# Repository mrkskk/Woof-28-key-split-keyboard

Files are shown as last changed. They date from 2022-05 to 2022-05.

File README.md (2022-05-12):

# Woof-28-key-split-keyboard

## Description

If you hate moving your entire hand to reach keys, this 28-key collumnar staggered keyboard is for you.

It lacks the inner index collumn, and the upper pinky key has been moved to an easier to reach position. 

## Photos:

woof
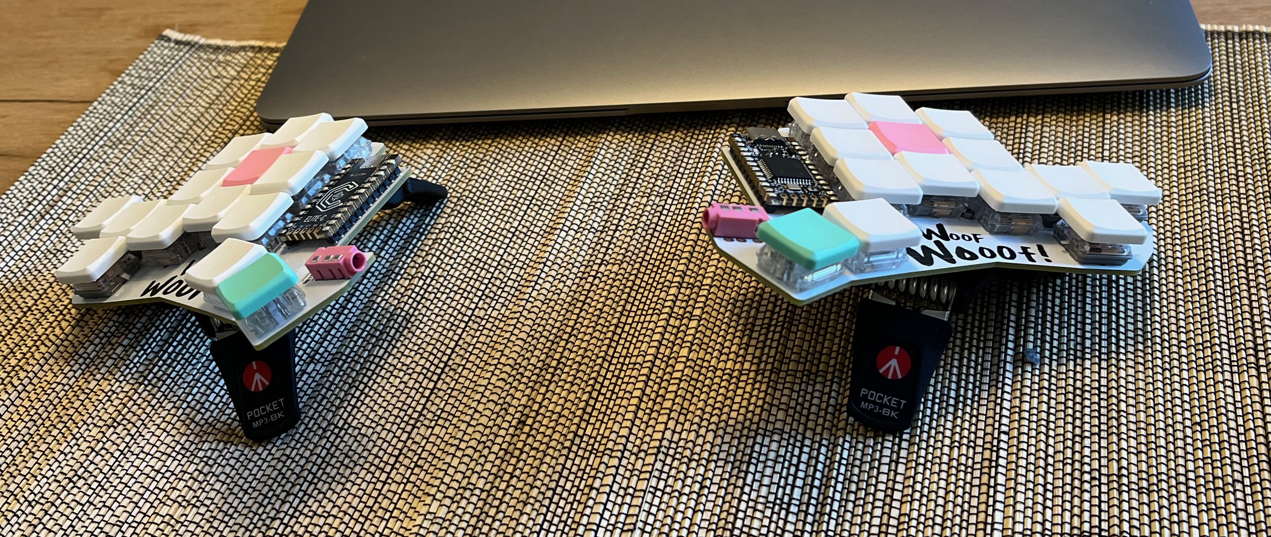
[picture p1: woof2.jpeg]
woof2

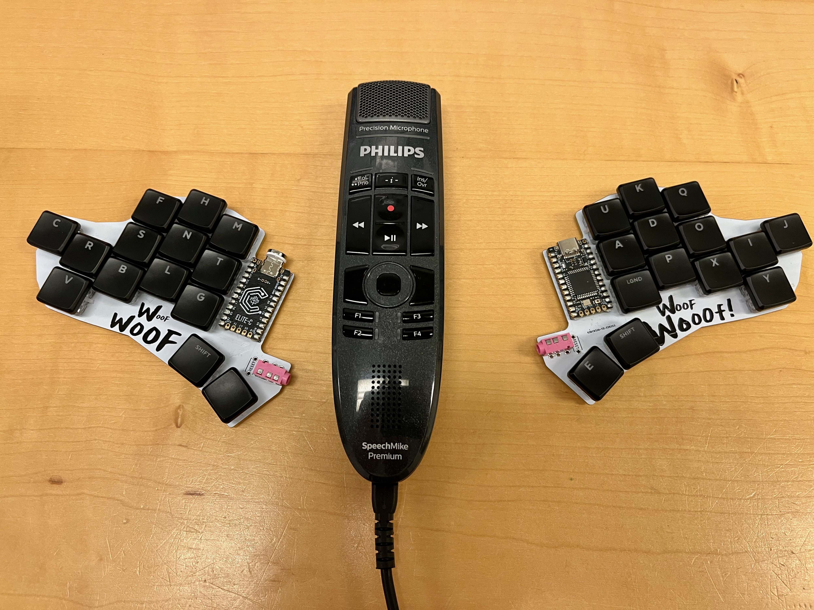
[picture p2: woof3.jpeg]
woof3


## Design Inspiration:

I named it woof since it sort of looks like a dog's head.

The keyboard uses the same staggering and keyspacing as the Ferris keyboard, but the inner index collumns have been removed. 

The upper row pinky keys have been moved to a position thats easier to reach. This is inspired by the Osprette, although the upper pinky key positions aren't the same.

Links:
* [Ferris, 34-key choc spaced keyboard](https://github.com/pierrechevalier83/ferris)
* [Osprette, 34-key unibody keyboard with pinky clusters](https://github.com/smores56/osprette)

## How to Print the circuit board

1. Download the gerber.zip file
2. Send it to a PCB manufacturer of your choice.
3. Pay and wait in patience

## How to build it

### Hardware requirements

* the PCB uploaded here
* Choc switches
* Choc compatible keycaps
* MCU: any ProMicro based MCU
* Optional: Battery, TRRS switch, TRRS cable, reset switch, 

### How to install the firmware

Either:
1. Use QMK. see my keymap below
OR
2. Use ZMK and make your own shield. the ZMK keymap is yet to be made

## My keymap

[QMK keymap](https://github.com/mrkskk/qmk_firmware/tree/my_branch/keyboards/woof)

## License
It is fully Open-Sourced.

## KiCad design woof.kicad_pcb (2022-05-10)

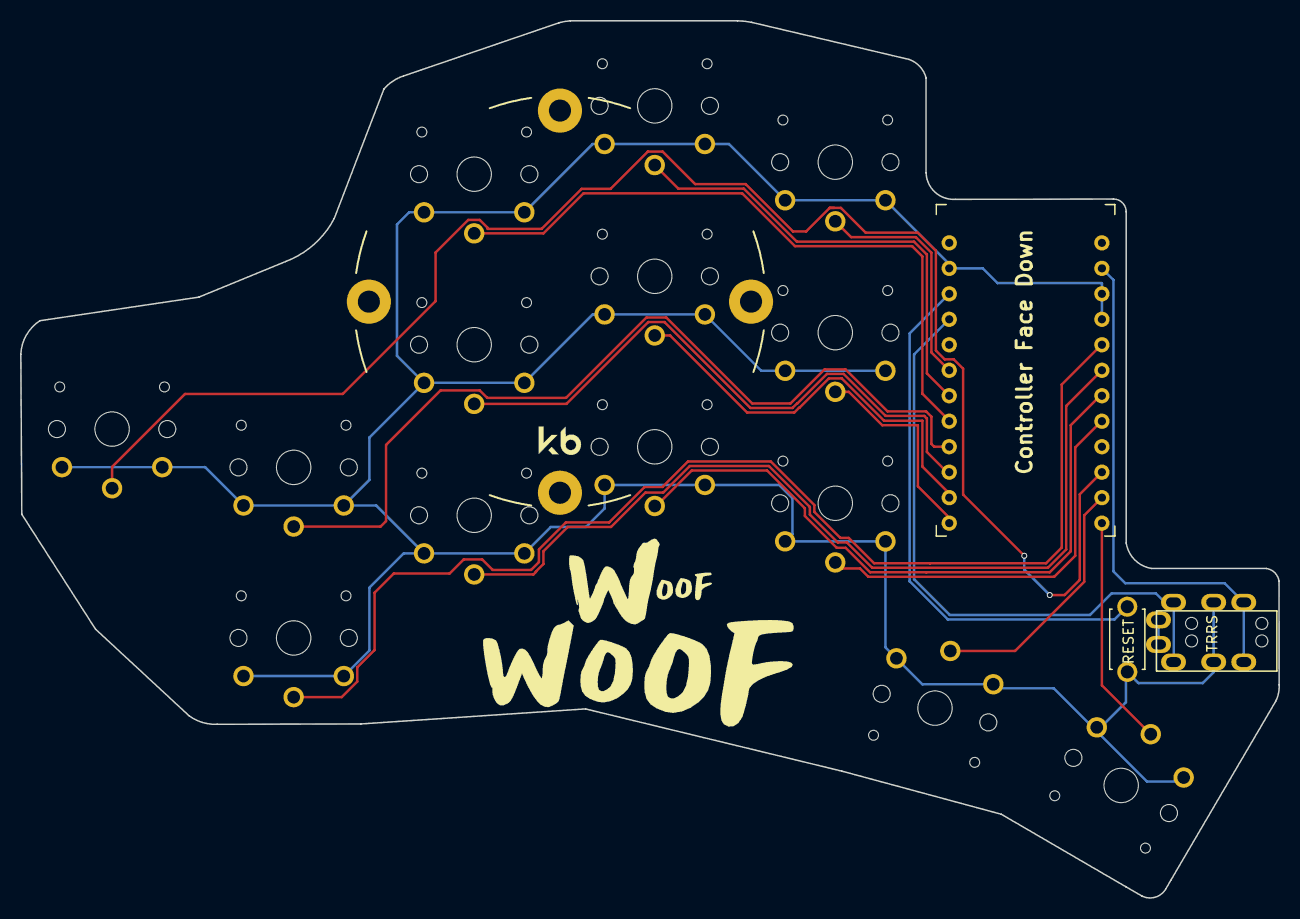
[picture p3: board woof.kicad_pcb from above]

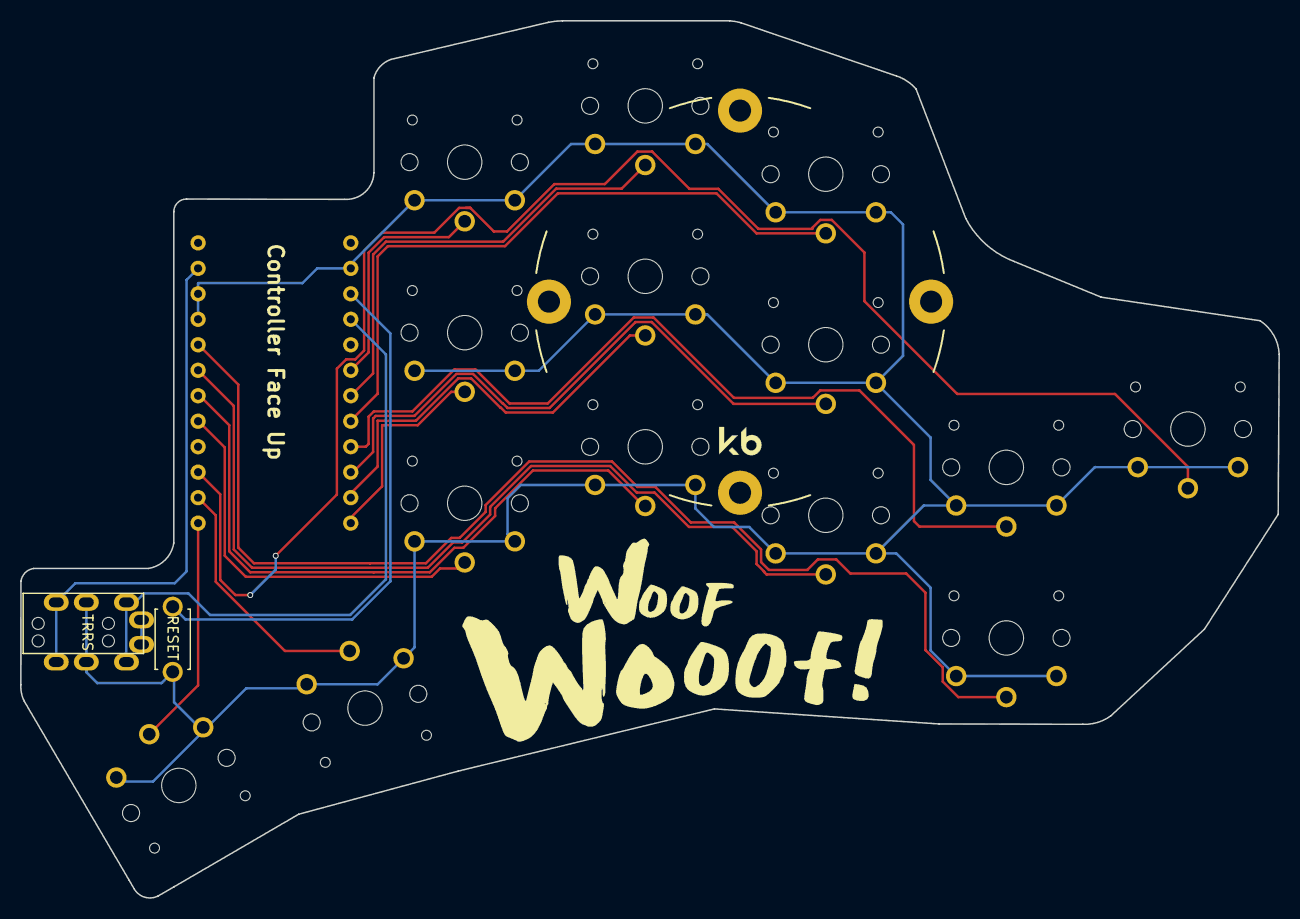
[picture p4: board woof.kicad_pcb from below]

Board: 2 copper layers, 125.5 x 87.4 mm, 17 parts (2 on the bottom side), 18 nets.

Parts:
J1: MJ-4PP-9
RSW1: Val**; ResetSW
SW2, SW3, SW4, SW5, SW8, SW9, SW10, SW11, SW14, SW15, SW16, SW17, SW20, SW21: SW_PUSH; SW_PG1350_reversible_b2
U1: ProMicro; ProMicro_v3

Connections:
GND: J1.C, RSW1.2, SW2.2, SW3.2, SW4.2, SW5.2, SW8.2, SW9.2, SW10.2, SW11.2, SW14.2, SW15.2, SW16.2, SW17.2, SW20.2, SW21.2, U1.3, U1.4, U1.23
unnamed: SW20.1, U1.11
unnamed: SW21.1, U1.12
unnamed: SW11.1, U1.13
unnamed: SW10.1, U1.14
SCL: SW15.1, U1.6
SDA: SW14.1, U1.5
VCC: J1.D, U1.21
col1: SW5.1, U1.19
col2: SW4.1, U1.18
col3: SW3.1, U1.17
col4: SW8.1, U1.16
col5: SW9.1, U1.15
data: J1.B, U1.2
reset: RSW1.1, U1.22
row0: SW16.1, U1.7
row1: SW17.1, U1.8
row3: SW2.1, U1.10
